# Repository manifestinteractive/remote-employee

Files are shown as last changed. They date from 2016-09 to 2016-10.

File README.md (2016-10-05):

Remote Employee
===

If you are a Remote Employee, like me, you likely are missed by your fellow employees.  Why not give them the next best thing? A super over the top Cutout of you they can stick in their office to talk to whenever they feel like it !!!

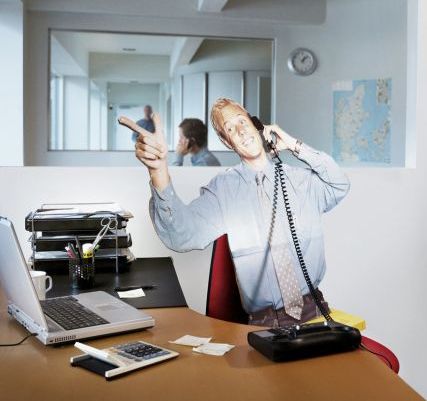
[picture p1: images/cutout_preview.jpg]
cutout_preview


__Your Cutout will help / annoy your fellow coworkers by:__

* Listening to what they have to say
* Having a Random Response

Table of Contents
---

* [Part List](#part-list)
* [Hardware Assembly](#hardware-assembly)
* [Wiring Instructions](#wiring-instructions)
* [Recording Voices](#recording-voices)
* [Software Installation](#software-installation)
* [Making a Cutout](#making-a-cutout)
* [Using your Remote Employee](#using-your-remote-employee)

Part List
---

**[⇧ back to top](#table-of-contents)**

#### You will need to purchase the following hardware:

* `ARD` [Arduino Uno R3](https://www.adafruit.com/products/50?utm_medium=referral&utm_source=manifestinteractive) _$24.95_
* `MP3` [Adafruit "Music Maker" MP3 Shield ( with amp )](https://www.adafruit.com/products/1788?utm_medium=referral&utm_source=manifestinteractive) _$34.95_
* `MIC` [Electret Microphone Amplifier - MAX4466](https://www.adafruit.com/products/1063?utm_medium=referral&utm_source=manifestinteractive) _$6.95_
* `SPK` [Speaker - 3" Diameter - 4 Ohm 3 Watt](https://www.adafruit.com/products/1314?utm_medium=referral&utm_source=manifestinteractive) _$1.95_

#### Other stuff you'll likely need:

* [Micro SD Card ( 2GB )](http://www.amazon.com/Sandisk-2GB-Micro-Sd-Card/dp/B000N3LL02) _$7.95_
* [Arduino Project Enclosure](https://www.amazon.com/Arduino-06RBARD16-Box/dp/B003ZKJNVY) _$13.63_

Hardware Assembly
---

**[⇧ back to top](#table-of-contents)**

There are really good writeups by Adafruit on how to assemble the hardware:

* [Attach MP3 Shield](https://learn.adafruit.com/adafruit-music-maker-shield-vs1053-mp3-wav-wave-ogg-vorbis-player?view=all)
* [Attach Microphone](https://learn.adafruit.com/3d-printed-led-microphone-flag?view=all)

Wiring Instructions
---

**[⇧ back to top](#table-of-contents)**

Since the `MP3` shield will be placed directly on top of the `ARD` Arduino, you will need to hook everything up using the following method:

| Part | Pin | > | Part | Pin  | Cable  |
|---|---|---|---|---|---|
| MIC  | VCC | > | MP3  | 3.3V | Red |
| MIC  | GND | > | MP3  | GND  | Black  |
| MIC  | AUD | > | MP3  | A0 | White  |
| SPK  | - | > | MP3  | - | Red |
| SPK  | + | > | MP3  | + | Black  |

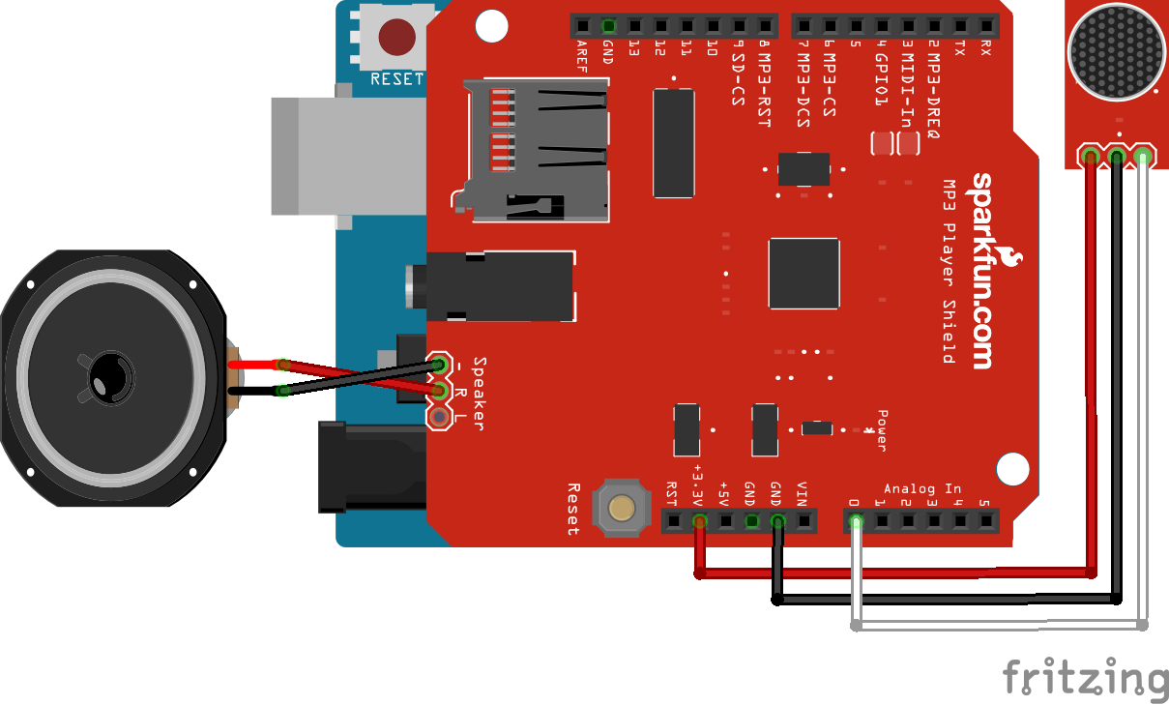
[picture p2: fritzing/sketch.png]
wiring


Recording Voices
---

**[⇧ back to top](#table-of-contents)**

The `MP3` device can hold up to 2GB of audio files so you can record as many as you want to fill up this 2GB card ( which is the largest size this MP3 shield supports ).  The MP3 shield also has a weird caveat where the file names must be exactly 8 characters in length. For that reason I was naming the files `00000001.mp3` - `99999999.mp3`.  The software on the Arduino will automatically figure out how many files you have on the SD card.  So as long as you start the numbering with `00000001.mp3` you can have up to 99,999,999 mp3 files ... which is WAY WAY more files thant you can actually put on a 2GB card.

As far as the how to actually record the audio files, you can use your Smart Phone to just record a few phrases you think would be fun to have.  Just keep in mind that you want to not have a whole lot of noise in the background, and you will likely want to make sure you are only recording what you want in the MP3 file.

There is a Free online audio converter at [http://media.io](http://media.io) if you need to convert your audio files.

Software Installation
---

**[⇧ back to top](#table-of-contents)**

Before you install the software onto your Arduino Uno, you will want to copy all the audio files in the [./sounds](sounds) folder into the root of your Micro SD Card, then insert the SD Card into the MP3 Shield.  Make sure not to put the files in any folders on the SD card.  They should be directly in the root of the card.

Once you have all the hardware installed, you just need to open the [./sketch/sketch.ino](sketch/sketch.ino) file in your [Arduino Code Editor](https://www.arduino.cc/en/Main/Software).  Now you just need to upload the sketch to your Arduino Uno.

Making a Cutout
---

**[⇧ back to top](#table-of-contents)**

This part is up to you, but you should have fun with it !!!

* You will need a camera that can take super high resolution pictures
* Take a LOT of different pictures and find the one you like best
* Use a Photo Editing program like PhotoShop and crop out the background so that only you are left
* Ask a Sign Making Company in your area to print your image using Corrugated PVC, or some other sturdy material ( if you use Cardboard it will get destroyed pretty quickly ) and ask them to make the cutout to the size you need ( if you are doing Life Size, give them your height )
* Once the cutout is complete, attach the hardware to the back of the cutout and add some power !!!

**Here was my process ( Total $120 ):**

* I went [FASTSIGNS](https://www.fastsigns.com)
* Made image 300 DPI at Actual Printed Dimensions ( 28" x 28" )
* Ordered Vinyl Printed PVC Easel Backed Tabletop Cut Out with a Contour Cut

Using your Remote Employee
---

**[⇧ back to top](#table-of-contents)**

The voices are set to randomly play once the microphone detects talking has stopped.  Here is a break down of the basic logic for voice detection:

1. There is a running sample average of the microphone
2. Volume average peeks above average room noise
3. Above average volume continues for a second or more ( to prevent false triggering on quick loud sounds )
4. Wait for volume average to go back below speaking threshold
5. Please random audio clip

There is also logic in place to not pay attention to the audio sampling while an audio clip is playing ( otherwise it would also trigger that someone is talking ).

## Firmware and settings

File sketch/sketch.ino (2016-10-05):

// include SPI, MP3 and SD libraries
#include <SPI.h>
#include <Adafruit_VS1053.h>
#include <SD.h>

// These are the pins used for the music maker shield
#define SHIELD_RESET  -1 // VS1053 reset pin (unused!)
#define SHIELD_CS     7  // VS1053 chip select pin (output)
#define SHIELD_DCS    6  // VS1053 Data/command select pin (output)

// These are common pins between breakout and shield
#define CARDCS 4 // Card chip select pin
#define DREQ 3   // VS1053 Data request, ideally an Interrupt pin

Adafruit_VS1053_FilePlayer musicPlayer = Adafruit_VS1053_FilePlayer(SHIELD_RESET, SHIELD_CS, SHIELD_DCS, DREQ, CARDCS);
File root;

// Default Settings

const int sampleWindow = 50;        // sample window width in mS (50 mS = 20Hz)
const int numReadings = 10;         // how many samples to take for creating the average
long randNumber;                    // randomly Generated Number

unsigned int volume = 0;            // weird Volume stuff where the lower the number, the higher the volume ( yep, seriously )
unsigned int sample;                // last recorded sample
unsigned int readings[numReadings]; // the readings from the analog input
unsigned int readIndex = 0;         // the index of the current reading
unsigned int total = 0;             // the running total
unsigned int average = 0;           // the average
unsigned int talkTime = 0;          // counter to track how long person was talking
unsigned int talkTimeMin = 10;      // how long a person needs to talk before we play a clip
unsigned int talkThreshold = 40;    // the volume level expected for talking
unsigned int minWaitTime = 60;      // minimum time between playback
unsigned int curWaitTime = 0;       // current time between playback
unsigned int numMP3files = 0;

boolean initialized = false;        // disable actual audio playback for development
boolean mute = false;               // disable actual audio playback for development
boolean debug = false;              // use this to debug output in serial monitor
boolean debugLevels = false;        // whether to debug microphone levels
boolean startedTalking = false;     // person started talking above talkThreshold
boolean finishedTalking = false;    // person finished talking above talkThreshold
boolean waitCheck = false;          // should wait for a bit before next response played
boolean playClip = false;           // whether talking went on above talkThreshold longer than talkTimeMin
boolean playedClip = false;         // whether a clip was actually played

// Store Previously Played MP3 files

String prevFile1;
String prevFile2;
String prevFile3;
String prevFile4;
String prevFile5;

void setup() {
  Serial.begin(9600);

  if (! musicPlayer.begin()) {
    if (debug) Serial.println(F("Unable to detect MP3 Player.  Check wiring."));
    while (1);
  }

  SD.begin(CARDCS);

  musicPlayer.setVolume(volume, volume);
  musicPlayer.useInterrupt(VS1053_FILEPLAYER_PIN_INT);

  for (int thisReading = 0; thisReading < numReadings; thisReading++) {
    readings[thisReading] = 0;
  }

  // Make "random" a little more random
  randomSeed(analogRead(0));

  // Get Count of Audio Files
  root = SD.open("/");
  countFiles(root);
}

void loop() {
  if (initialized) {
    unsigned long startMillis= millis();
    unsigned int peakToPeak = 0;
  
    unsigned int signalMax = 0;
    unsigned int signalMin = 1024;
  
    // collect data for 50 mS
    while (millis() - startMillis < sampleWindow) {    
      sample = analogRead(0);
      if (sample < 1024) {
        if (sample > signalMax) {
          signalMax = sample;
        } else if (sample < signalMin) {
          signalMin = sample;
        }
      }
    }
  
    peakToPeak = signalMax - signalMin;
  
    // generate false reading of low volume when playing audio clip
    if (!musicPlayer.stopped()) {
      peakToPeak = 0;
    }
  
    total = total - readings[readIndex];
    readings[readIndex] = peakToPeak;
    total = total + readings[readIndex];
    readIndex = readIndex + 1;
  
    if (readIndex >= numReadings) {
      readIndex = 0;
    }
  
    average = total / numReadings;
  
    // Check for starting a new conversation
    if (average >= talkThreshold && !startedTalking) {
      startedTalking = true;
      if (debug) Serial.println("Started Talking");
    }
  
    // Check that talking went on long enough to play a clip
    if (average >= talkThreshold && startedTalking && !finishedTalking && !playClip) {
      talkTime++;
  
      if (talkTime >= talkTimeMin) {
        playClip = true;
        if (debug) Serial.println("Talked Long Enough to Play Response");
      }
    }
  
    // Check that talking has finished
    if (startedTalking && !finishedTalking && average < talkThreshold && !waitCheck) {
      finishedTalking = true;
      if (debug) Serial.println("Finished Talking");
  
      if (playClip) {
        String playFile = randomFile(0);
        if (playFile.length() == 12) {
          char fileName[13];
          playFile.toCharArray(fileName, 13);
          playMP3(fileName);
        } else {
          if (debug) Serial.println("Invalid File Name");
          resetTalking();
        }      
      } else {
        resetTalking();
      }
    } else if (waitCheck) {
      if (curWaitTime < minWaitTime) {
        curWaitTime++;
        resetTalking();
      } else {
        curWaitTime = 0;
        waitCheck = false;
      }
    }
  
    // Check if we were playing an audio file
    if (finishedTalking && playClip && musicPlayer.stopped() && playedClip) {
      if (debug) Serial.println("Done Playing Response");
      waitCheck = true;
      resetTalking();
    } else if (finishedTalking && playClip && !musicPlayer.stopped() && !playedClip) {
      if (debug) Serial.println("Playing Response");
      playedClip = true;
    }
  
    if (debug && debugLevels) {
      Serial.print("talkTime: ");
      Serial.print(talkTime);
  
      Serial.print(", average: ");
      Serial.print(average);
  
      Serial.print(", playClip: ");
      Serial.print(playClip);
  
      Serial.print(", playedClip: ");
      Serial.print(playedClip);
  
      Serial.print(", startedTalking: ");
      Serial.print(startedTalking);
  
      Serial.print(", finishedTalking: ");
      Serial.print(finishedTalking);
  
      Serial.println("");
    }
  } else {
    if (debug) Serial.println("Initializing ...");
  }
}

/**
 * Reset Talking State
 */
void resetTalking() {
  talkTime = 0;
  startedTalking = false;
  finishedTalking = false;
  playClip = false;
  playedClip = false;
}

/**
 * Play MP3 File with Specified `fileName`
 */
void playMP3(char* fileName){
  musicPlayer.stopPlaying();
  if (debug) {
    Serial.print("playMP3: ");
    Serial.println(fileName);
  }
  
  if (SD.exists(fileName) && !mute) {
    musicPlayer.startPlayingFile(fileName);
  } else if(mute) {
    resetTalking();
    if (debug) Serial.println("Audio Muted");
  } else if(!SD.exists(fileName)) {
    resetTalking();
    if (debug) Serial.println("Missing Audio File");
  }
}

/**
 * Create a Random File Name based on `numMP3files` count 
 */
String randomFile (int attempt) {
  randNumber = random(1, numMP3files+1);

  String prefix = leftPad(randNumber);
  String suffix = ".mp3";
  String playFile = prefix + suffix;

  // add some checks to make sure we are not playing the same files over and over
  if (playFile != prevFile1 && playFile != prevFile2 && playFile != prevFile3 && playFile != prevFile4 && playFile != prevFile5) {
    prevFile5 = prevFile4;
    prevFile4 = prevFile3;
    prevFile3 = prevFile2;
    prevFile2 = prevFile1;
    prevFile1 = playFile;
    
    return playFile;
  } else if (attempt <= 5) {
    if (debug) Serial.println("Random Audio Attempt #" + attempt);
    return randomFile(attempt+1);
  } else if (attempt >= 5) {
    resetTalking();
    if (debug) Serial.println("Giving Up");
  }
}

/**
 * Pass over Random Number and pad with leading zeros
 */
char * leftPad (int num) {
  static char strOut[8];

  if (num >= 0 && num < numMP3files) {
    sprintf(strOut, "%08d", num);
  }

  return strOut;
}

/**
 * Count MP3 files in the root directory
 */
void countFiles(File dir) {
  while (true) {

    File entry =  dir.openNextFile();
    if (! entry) {
      break;
    }

    if (!entry.isDirectory()) {      
      String fileName = entry.name();
      fileName.toLowerCase();

      if (fileName.length() == 12 && fileName.endsWith(".mp3")) {
        numMP3files++;
      }
    }

    entry.close();
  }

  initialized = true;
}

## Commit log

2016-09-26 Initial Commit of Remote Employee
    [sketch.fzz]
2016-10-05 Updated Sketch:
    * Arduino does not have to know how many files are loaded on the SD Card
    * File names are now just 8 numeric length names with zero left pads
    * Updated README to reflect new changes
